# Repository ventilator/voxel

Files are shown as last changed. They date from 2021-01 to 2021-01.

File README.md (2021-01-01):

# voxel
A piece of art - 3D printed cubes, semitransparent, arranged in pattern and LED light

48 cubes, back light LEDs, slowly changing their base color, fading in and out, giving a nice, non distracting back ground mood setting for a room

running (2)

cycling through the color wheel every 15min (or so)

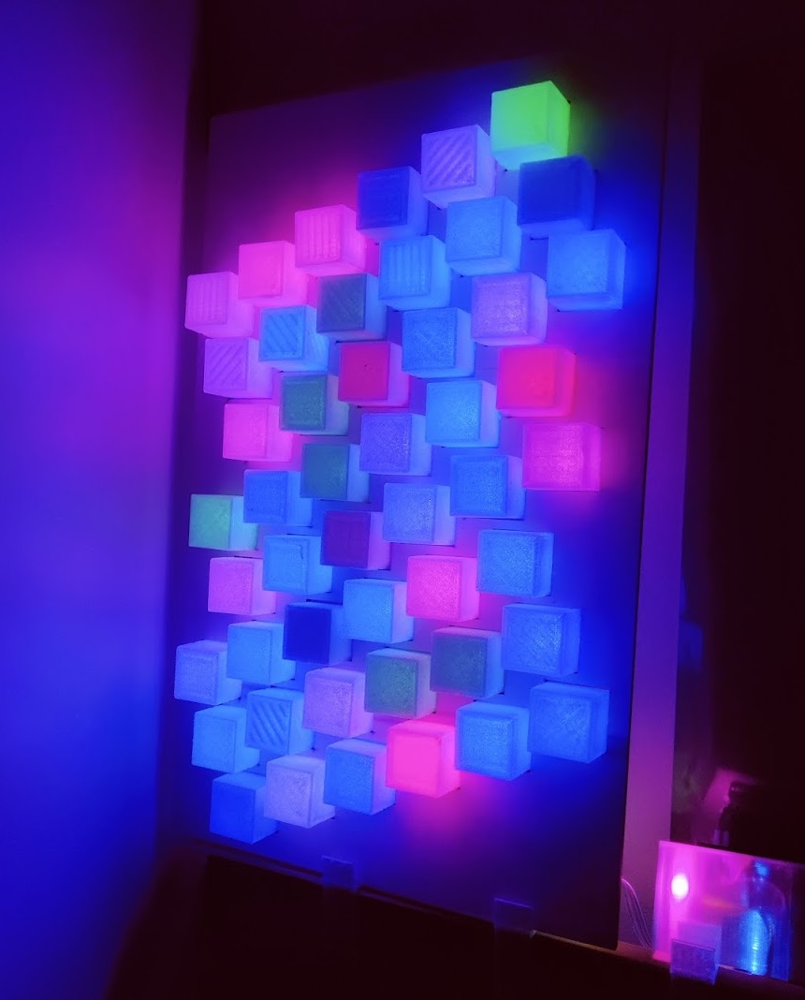
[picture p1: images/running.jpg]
running


## Material

### cube

Transparent filament (Prusament PETG Clear)

### backplane

wood (3mm)

### LEDs

WS2813 (50 LEDs, single LEDs with a diffusor cap)

### µController

Arduino Nano
Prototyping PCB, USB port, USB cable

### parameter case

Optional housing for the Arduino and and some old mechanical fader for parameter adjusting

## Assembly

hot glue (lots of)

solder

## Code

FastLED library for Arduino example code, modified to support parameter settings via analog faders on analog input (potentiometer)

## Backplate

generated with Processing to reflect a [Pythagorean tiling](https://en.wikipedia.org/wiki/Pythagorean_tiling)

laser cutter to cut from wood. The cubes have an edge length of 31.5mm, the squares are cut to be 31.7mm (just check for laser cutter file if dpi was set correctly)

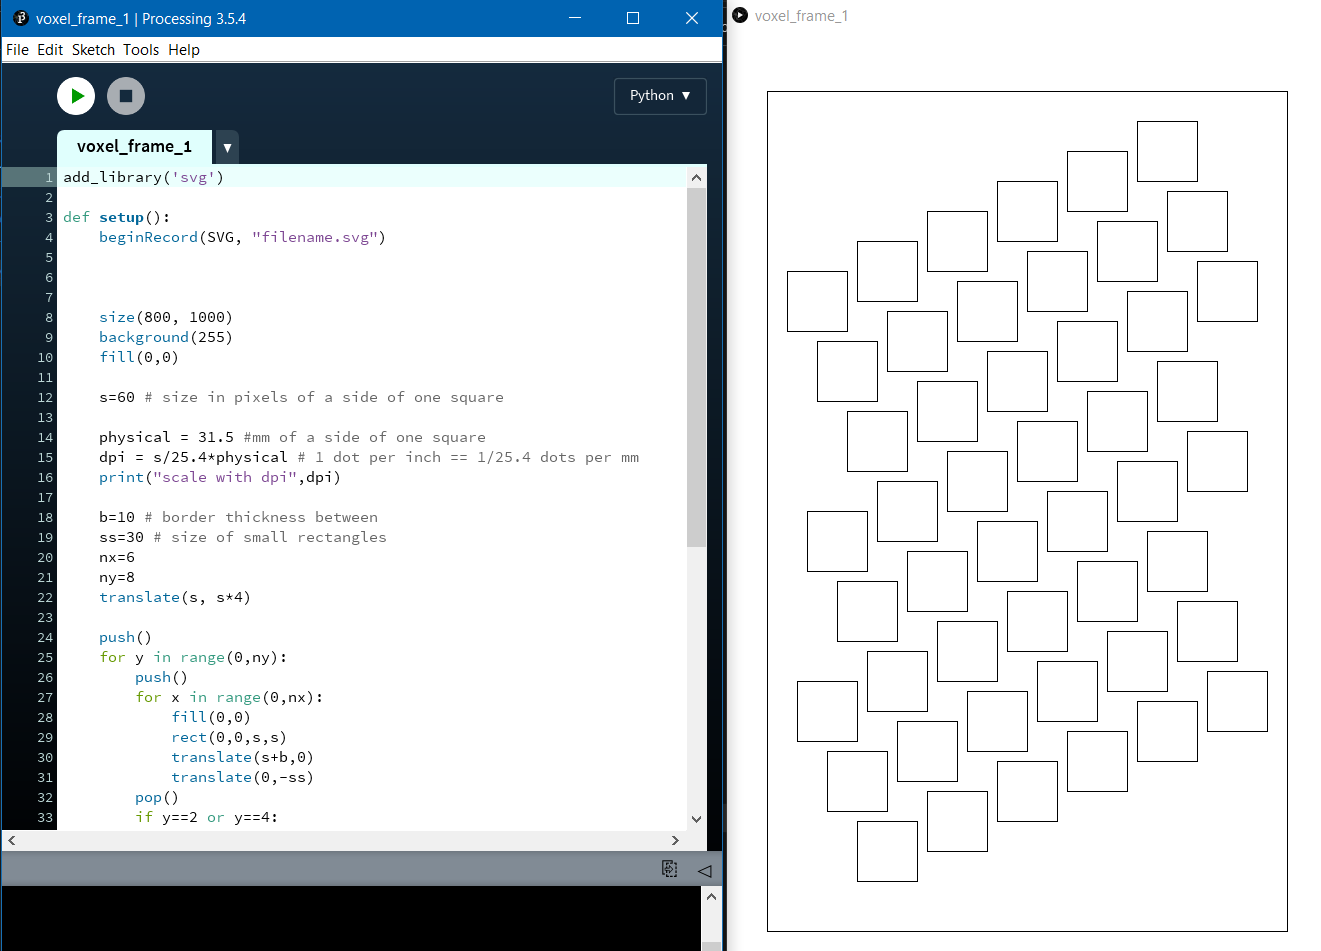
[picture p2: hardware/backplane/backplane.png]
backplane


### Cubes

generated with Fusion360, interesting part is the 3D Printing part:

A did a lot of experimenting for the correct look, since they are semitransparent, be careful about the surface structure

* fill pattern, top and bottom fill should be "Hilbert Curve", other infills generate ugly stripes and even worse: depending on the rotation on the print plate stripes with different angles. See first image, look closely to the surface to see the differences, there are some "beta cubes" in the assembly
* If available, use a textured sheet on your printer, this gives a better "frosted glass" look
* 3 cubes fit on a Prusa Mini if you rotated them as shown here

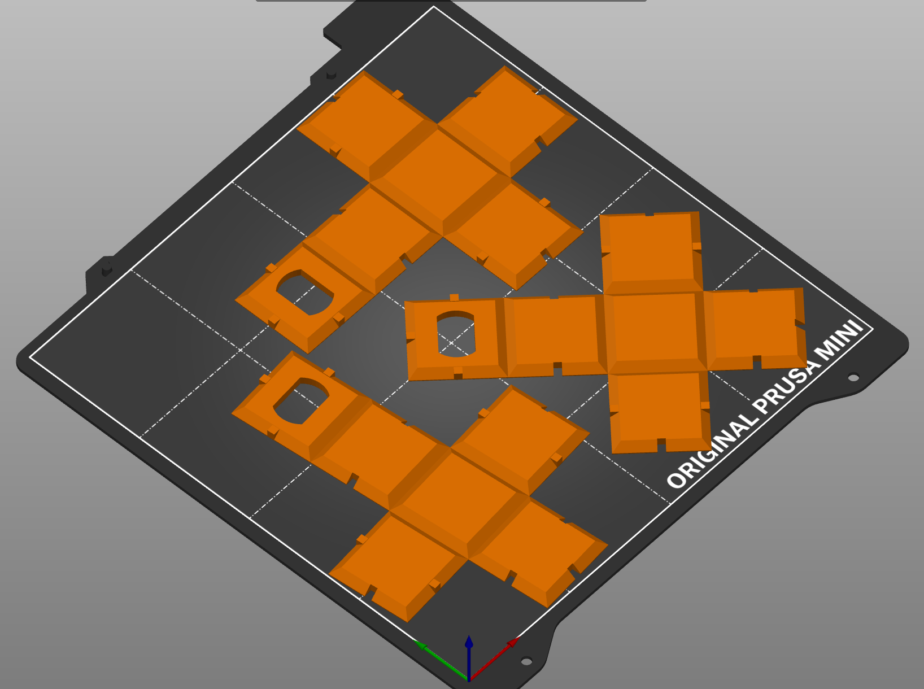
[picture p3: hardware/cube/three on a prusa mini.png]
three on a prusa mini


Once printed, just fold them. They should snap together and are held in place by the back plate (snug fit)

### Assembly

Use lots of hot glue

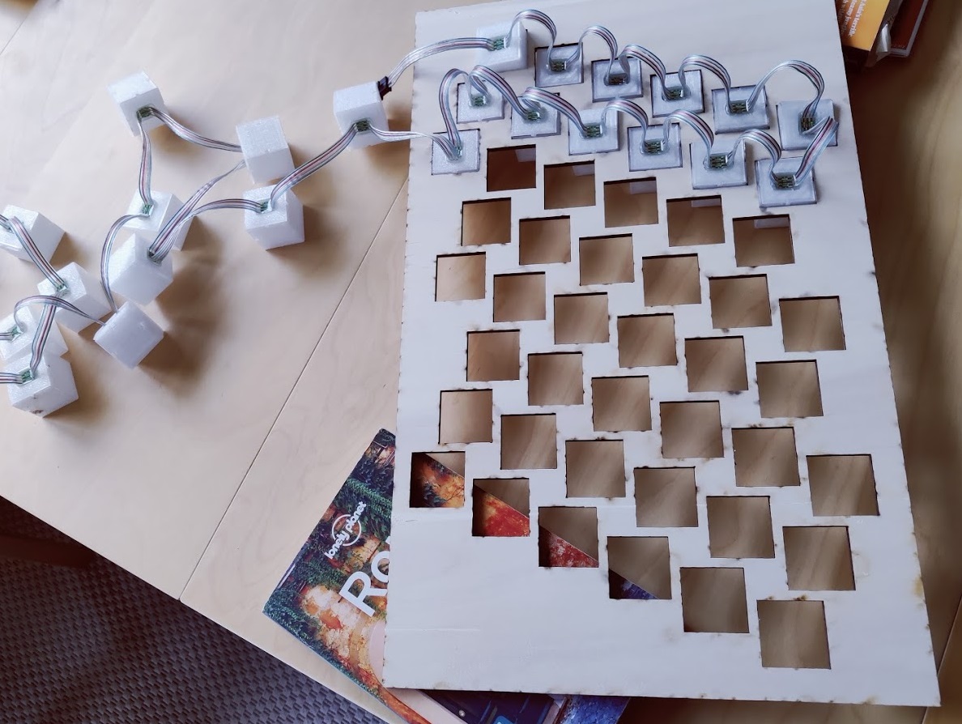
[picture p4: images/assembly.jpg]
assembly


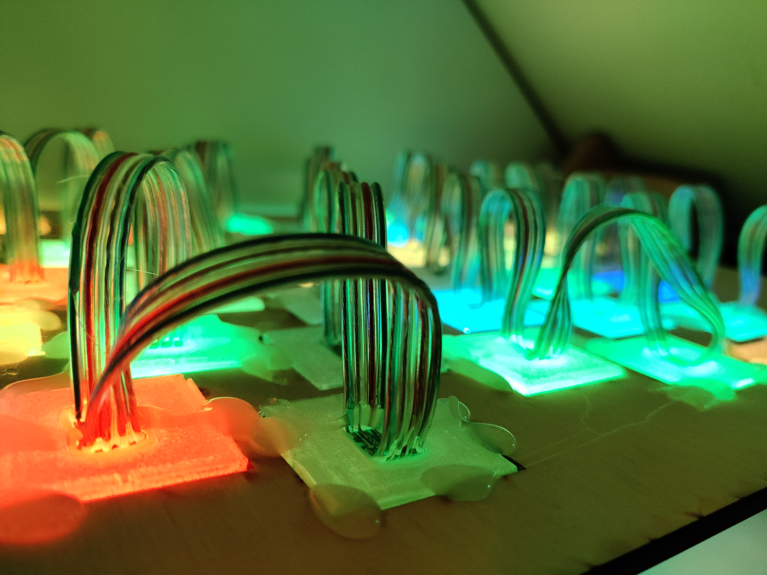
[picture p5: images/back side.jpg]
back side


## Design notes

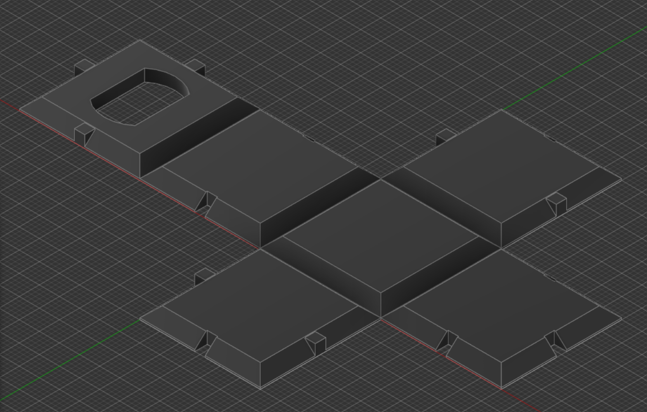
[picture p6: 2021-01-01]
hardware/cube/voxel.png

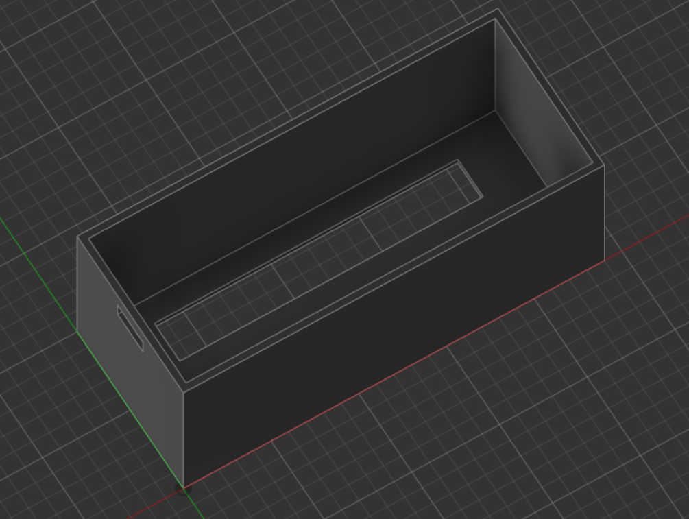
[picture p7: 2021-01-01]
hardware/case for fader and arduino/voxel-case.png

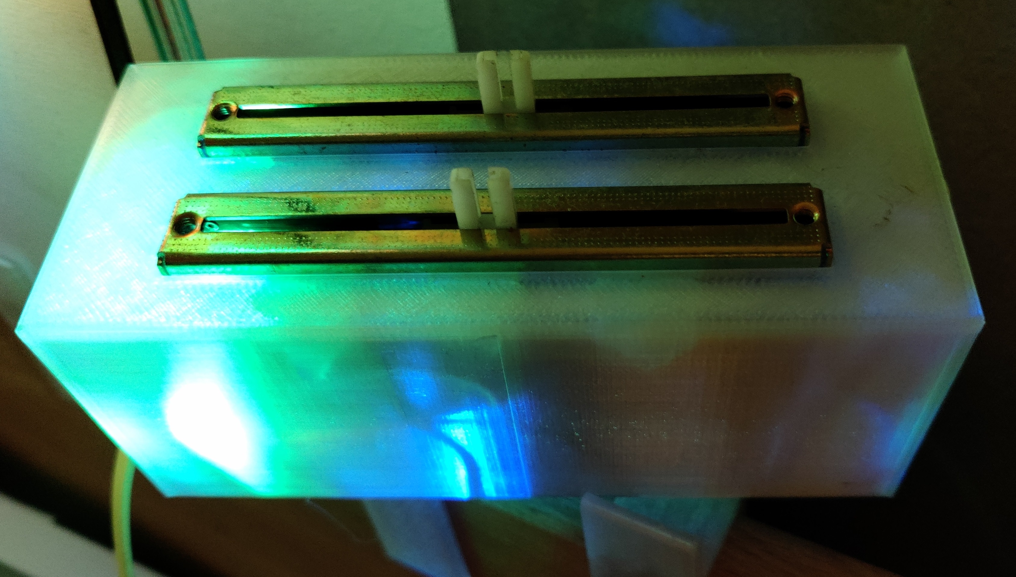
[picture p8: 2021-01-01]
images/parameter box (optional).jpg

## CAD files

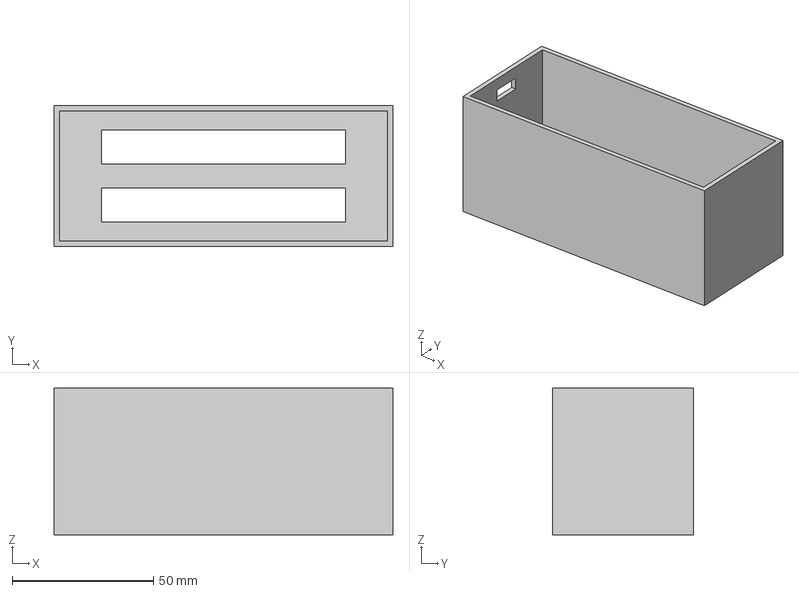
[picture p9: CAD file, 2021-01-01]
hardware/case for fader and arduino/source/case.step
120.0 x 50.0 x 52.0 mm

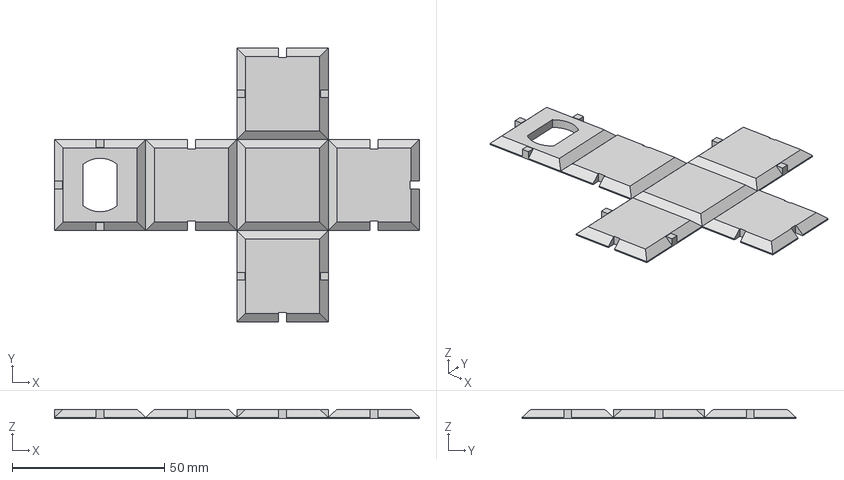
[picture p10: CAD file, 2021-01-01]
hardware/cube/source/LedVoxel.step
120.0 x 90.0 x 3.00 mm

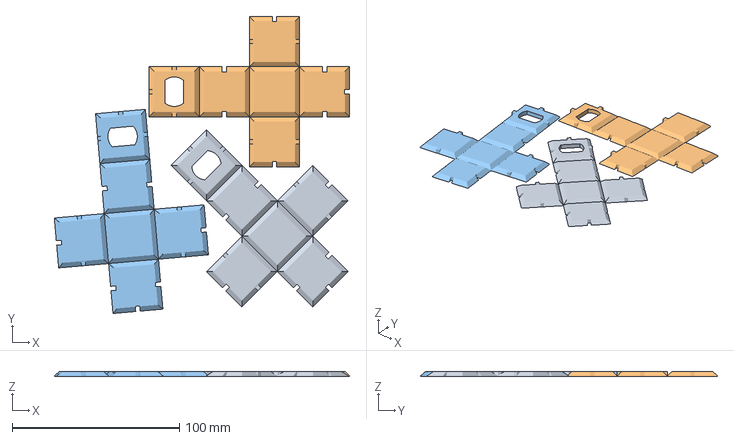
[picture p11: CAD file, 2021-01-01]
hardware/cube/x3_LedVoxel.3mf
176.8 x 177.7 x 3.00 mm
v0.3.stl x 3

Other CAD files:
hardware/case for fader and arduino/case.stl
hardware/case for fader and arduino/source/case.f3d
hardware/cube/LedVoxel.stl
hardware/cube/source/LedVoxel.f3d

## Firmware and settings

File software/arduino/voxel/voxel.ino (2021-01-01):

// #define FASTLED_INTERNAL enable this to disable pragma message
#include <FastLED.h>
// venti 2020-12-06
// takes demo reel, modified to slow down and only use confetti
// add hardware fader support for settings

FASTLED_USING_NAMESPACE

// FastLED "100-lines-of-code" demo reel, showing just a few 
// of the kinds of animation patterns you can quickly and easily 
// compose using FastLED.  
//
// This example also shows one easy way to define multiple 
// animations patterns and have them automatically rotate.
//
// -Mark Kriegsman, December 2014

#if defined(FASTLED_VERSION) && (FASTLED_VERSION < 3001000)
#warning "Requires FastLED 3.1 or later; check github for latest code."
#endif

#define DATA_PIN    12
//#define CLK_PIN   4
#define LED_TYPE    WS2812
#define COLOR_ORDER GRB
#define NUM_LEDS    50 //50
CRGB leds[NUM_LEDS];

#define BRIGHTNESS          80
//#define FRAMES_PER_SECOND  1 //120
//#define FADE_IN_DELAY 5
//#define FADE_OUT_DELAY 20

int FRAMES_PER_SECOND = 1;
int analog_pin_frames = A0;

int FADE_IN_DELAY = 5;
int FADE_OUT_DELAY_FACTOR = 2; //factor of fade_in_delay, e.g. FADE_IN_DELAY*4
int analog_pin_fade = A1;
int analog_fade = 500;

int debug_led_only = false;

void setup() {
  delay(3000); // 3 second delay for recovery, e.g. firmware flash  
  // tell FastLED about the LED strip configuration
  FastLED.addLeds<LED_TYPE,DATA_PIN,COLOR_ORDER>(leds, NUM_LEDS).setCorrection(TypicalLEDStrip);
  //FastLED.addLeds<LED_TYPE,DATA_PIN,CLK_PIN,COLOR_ORDER>(leds, NUM_LEDS).setCorrection(TypicalLEDStrip);
  // set master brightness control
  FastLED.setBrightness(BRIGHTNESS);
  Serial.begin(9600);  
}


// List of patterns to cycle through.  Each is defined as a separate function below.
typedef void (*SimplePatternList[])();
SimplePatternList gPatterns = { rainbow, rainbowWithGlitter, confetti, sinelon, juggle, bpm };

uint8_t gCurrentPatternNumber = 0; // Index number of which pattern is current
uint8_t gHue = 0; // rotating "base color" used by many of the patterns
  
void loop()
{
  // Call the current pattern function once, updating the 'leds' array
  gCurrentPatternNumber = 2; //confetti
  gPatterns[gCurrentPatternNumber]();

  // send the 'leds' array out to the actual LED strip
  FastLED.show();  
  // insert a delay to keep the framerate modest
  if (FRAMES_PER_SECOND<1) {FRAMES_PER_SECOND=1;} //dont let them become 0 because of division 
  FastLED.delay(512/FRAMES_PER_SECOND); 

  // do some periodic updates
  EVERY_N_MILLISECONDS( 2000 ) { gHue++; } // slowly cycle the "base color" through the rainbow
  //EVERY_N_SECONDS( 10 ) { nextPattern(); } // change patterns periodically

  //read fps
  int fps = analogRead(analog_pin_frames); //min 10 max 990
  if (fps<15) { fps=1; } // dont let them become 0 because of division
  if (fps>990) { fps=1024; }
  FRAMES_PER_SECOND = fps;
  Serial.print("fps: ");
  Serial.println(FRAMES_PER_SECOND);

  //read fade
  analog_fade = analogRead(analog_pin_fade); //min 10 max 990
  if (analog_fade<15) { analog_fade=1; }
  if (analog_fade>990) { analog_fade=1024; }
//  Serial.print("raw analog_fade: ");
//  Serial.println(analog_fade);  
  FADE_IN_DELAY = round(20*float(analog_fade)/1024);
  if (FADE_IN_DELAY<0) {FADE_IN_DELAY=0;}
  Serial.print("fade: ");
  Serial.println(FADE_IN_DELAY);  
}

#define ARRAY_SIZE(A) (sizeof(A) / sizeof((A)[0]))

void nextPattern()
{
  // add one to the current pattern number, and wrap around at the end
  gCurrentPatternNumber = (gCurrentPatternNumber + 1) % ARRAY_SIZE( gPatterns);
}

void rainbow() 
{
  // FastLED's built-in rainbow generator
  fill_rainbow( leds, NUM_LEDS, gHue, 7);
}

void rainbowWithGlitter() 
{
  // built-in FastLED rainbow, plus some random sparkly glitter
  rainbow();
  addGlitter(80);
}

void addGlitter( fract8 chanceOfGlitter) 
{
  if( random8() < chanceOfGlitter) {
    leds[ random16(NUM_LEDS) ] += CRGB::White;
  }
}

void confetti() 
{
  // random colored speckles that blink in and fade smoothly
  fadeToBlackBy( leds, NUM_LEDS, 1);
  int pos = random16(NUM_LEDS);
  if (debug_led_only) {
    pos = 5;
  }
  int new_hue = gHue + random8(64);
  if (random8(24)==0){
    new_hue = new_hue+128;
  }
  //read existing color (should be some faded pixel)
  uint8_t luma = leds[pos].getLuma();
  Serial.print("current luma: ");
  Serial.println(luma);
  //fade brightness to 0
  int fading=0;  
  luma=60;
  for (int b=0; b<luma; b++) {
    //leds[pos].fadeLightBy(5); //its amount of reduction on actual value of x/256
    leds[pos].nscale8_video(250);
    fading++;    
    FastLED.show(); 
    FastLED.delay(FADE_IN_DELAY*FADE_OUT_DELAY_FACTOR);
  }
  Serial.print("faded steps, waiting 250ms: ");
  Serial.println(fading);
  FastLED.delay(250);
  //fade brightness with new hue to 255
  int step_ = 1;
  luma = leds[pos].getLuma();
  Serial.print("current luma: ");
  Serial.println(luma);  
  for (int v=100; v<255-step_; v=v+step_) {
    leds[pos] = CHSV( new_hue, 200, v);
    FastLED.show(); 
    FastLED.delay(FADE_IN_DELAY);
  }
}

void sinelon()
{
  // a colored dot sweeping back and forth, with fading trails
  fadeToBlackBy( leds, NUM_LEDS, 20);
  int pos = beatsin16( 13, 0, NUM_LEDS-1 );
  leds[pos] += CHSV( gHue, 255, 192);
}

void bpm()
{
  // colored stripes pulsing at a defined Beats-Per-Minute (BPM)
  uint8_t BeatsPerMinute = 62;
  CRGBPalette16 palette = PartyColors_p;
  uint8_t beat = beatsin8( BeatsPerMinute, 64, 255);
  for( int i = 0; i < NUM_LEDS; i++) { //9948
    leds[i] = ColorFromPalette(palette, gHue+(i*2), beat-gHue+(i*10));
  }
}

void juggle() {
  // eight colored dots, weaving in and out of sync with each other
  fadeToBlackBy( leds, NUM_LEDS, 20);
  byte dothue = 0;
  for( int i = 0; i < 8; i++) {
    leds[beatsin16( i+7, 0, NUM_LEDS-1 )] |= CHSV(dothue, 200, 255);
    dothue += 32;
  }
}

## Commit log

2021-01-01 prototype #1
    [LedVoxel.f3d, LedVoxel.step, LedVoxel.stl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]
2021-01-01 add prusamini 3mf file
    [x3_LedVoxel.3mf]
